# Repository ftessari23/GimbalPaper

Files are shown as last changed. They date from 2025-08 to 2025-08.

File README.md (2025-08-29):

# Gimbal Device

This repository contains the design files and assembly details for the **Gimbal apparatus** used in our recent publication. The device was developed to study human wrist rotations in both **kinematics** and **dynamics** experiments.  

## 📂 Repository Contents
- **`BoM.xlsx`**  
  Bill of Materials (BoM) listing the off-the-shelf components used. These are the exact parts I sourced (U.S.-based suppliers), but they are **not the only options**—equivalent components may be substituted.  

- **`.sldprt` files**  
  Individual **SolidWorks part files** for each component.  

- **`.sldasm` file**  
  Complete **SolidWorks assembly file** for the gimbal system.  

- **`.stl` files**  
  Components for **3D printing**. I printed them on a **Bambu FDM printer** with PLA filament.  
  - Recommended infill: **60–75%** for structural strength.  
  - Settings may be tuned depending on intended use.  

## ⚠️ Notes & Limitations
- The current design is **functional but not perfect**.  
- The **handle–fork connection** is the weakest point and has been the main failure site in testing.  
- The apparatus performs **reliably in pushing tasks** (as demonstrated in the paper).  
- It is **not recommended for pulling tasks**, as the handle–fork connection is likely to fail under tensile loads.  

## 🔧 Future Improvements
- Reinforcement or redesign of the **handle–fork interface**.  
- Optimization of the printed components for higher fatigue resistance.  

## 🌍 Applications
This gimbal system may be useful for researchers interested in:  
- Studying **human wrist rotations**.  
- Designing experiments involving **joint kinematics** or **interaction dynamics**.  
- Exploring applications in **rehabilitation robotics** and **biomechanics**.  

## 🤝 Contributions
Feel free to **edit, improve, or update** any part of the design. Contributions and forks are welcome to refine the apparatus for broader use.  

## 📖 Citation
If you use this design in your work, please cite the associated publication:

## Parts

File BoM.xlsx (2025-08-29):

Provider | Name | Order nr | Quantity | Link | Price/pc. ($) | Price total ($)
McMaster Carr | Ultra-Thin Ball Bearing: 440 Stainless Steel Ring, Open, 10mm Shaft Diameter and 22mm Housing ID | 6656K75 | 4 | https://www.mcmaster.com/6656K75/ | 16.12 | 64.48
McMaster Carr | Permanently Lubricated Ball Bearing: Open, Trade Number 6001, for 12 mm Shaft Diameter | 2349K213 | 4 | https://www.mcmaster.com/2349K213/ | 21.7 | 86.8
McMaster Carr | One-Piece Thrust Ball Bearing Shielded, for 5/16" Shaft Diameter, 11/16" OD | 60715K111 | 2 | https://www.mcmaster.com/60715K111/ | 48.72 | 97.44
McMaster Carr | Inline Ball Joint Linkage M8 x 1.25 mm Thread | 8412K12 | 2 | https://www.mcmaster.com/8412K12/ | 11.7 | 23.4
McMaster Carr | External Retaining Ring for 8 mm OD, DIN 1.4122 Stainless Steel | 90967A120 | 1 | https://www.mcmaster.com/90967A120/ | 7.66 | 7.66
McMaster Carr | Headless Clevis Pin with Retaining Ring Groove 18-8 Stainless Steel, 4 mm Diameter, 24 mm Usable Length | 93890A731 | 2 | https://www.mcmaster.com/93890A731/ | 10.64 | 21.28
McMaster Carr | Clevis Pin with Retaining Ring Groove 18-8 Stainless Steel, 6 mm Diameter, 28 mm Usable Length | 92735A112 | 1 | https://www.mcmaster.com/92735A112/ | 8.45 | 8.45
McMaster Carr | Clevis Pin with Retaining Ring Groove 18-8 Stainless Steel, 6 mm Diameter, 33 mm Usable Length | 92735A113 | 1 | https://www.mcmaster.com/92735A113/ | 9.58 | 9.58
McMaster Carr | External Retaining Ring for 12 mm OD, Zinc-Chromate-Plated Spring Steel | 90154A273 | 1 | https://www.mcmaster.com/90154A273/ | 11.77 | 11.77
 |  |  |  |  | TOTAL ($) | 254.61

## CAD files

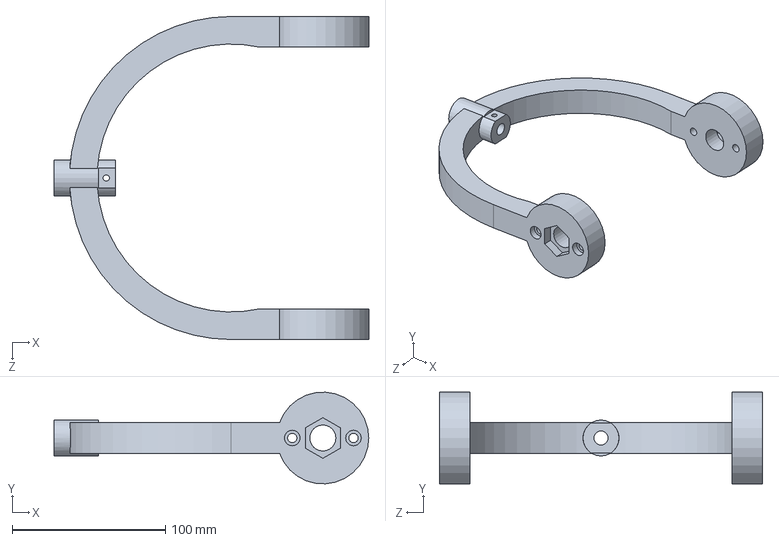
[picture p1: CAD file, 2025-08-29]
fork.SLDPRT
205.5 x 59.9 x 211.0 mm

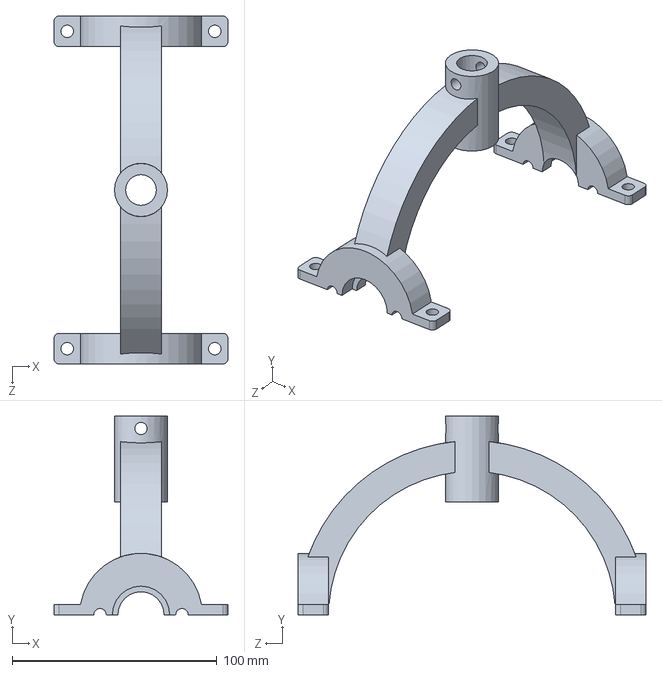
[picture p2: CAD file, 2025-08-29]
top_orbit.SLDPRT
85.0 x 97.0 x 170.0 mm

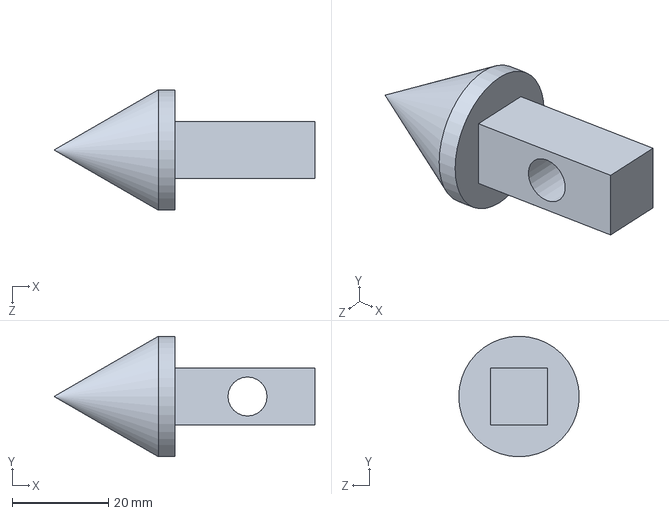
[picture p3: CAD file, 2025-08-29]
tool_end.SLDPRT
54.2 x 25.0 x 25.0 mm

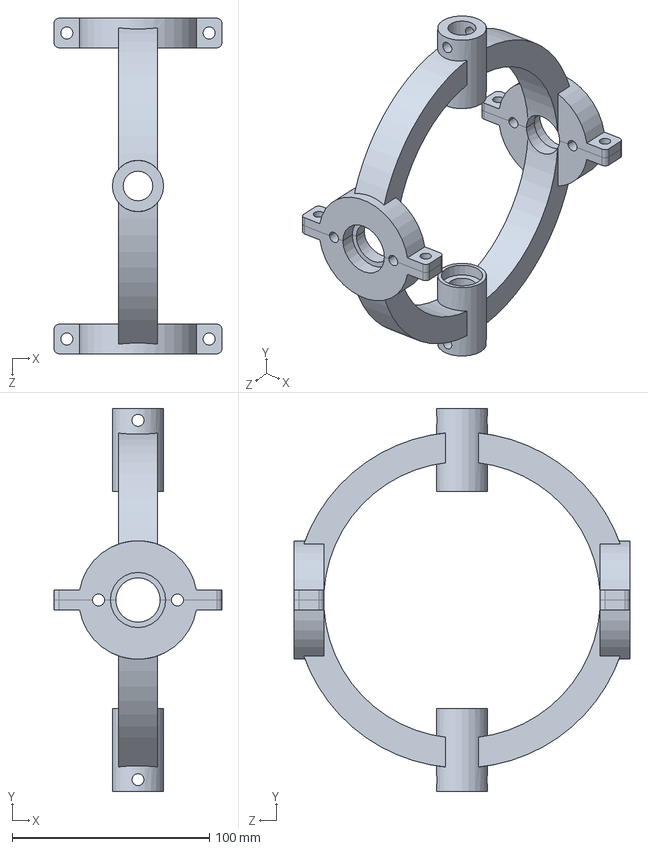
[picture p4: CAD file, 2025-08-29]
orbit.SLDPRT
85.0 x 194.0 x 170.0 mm

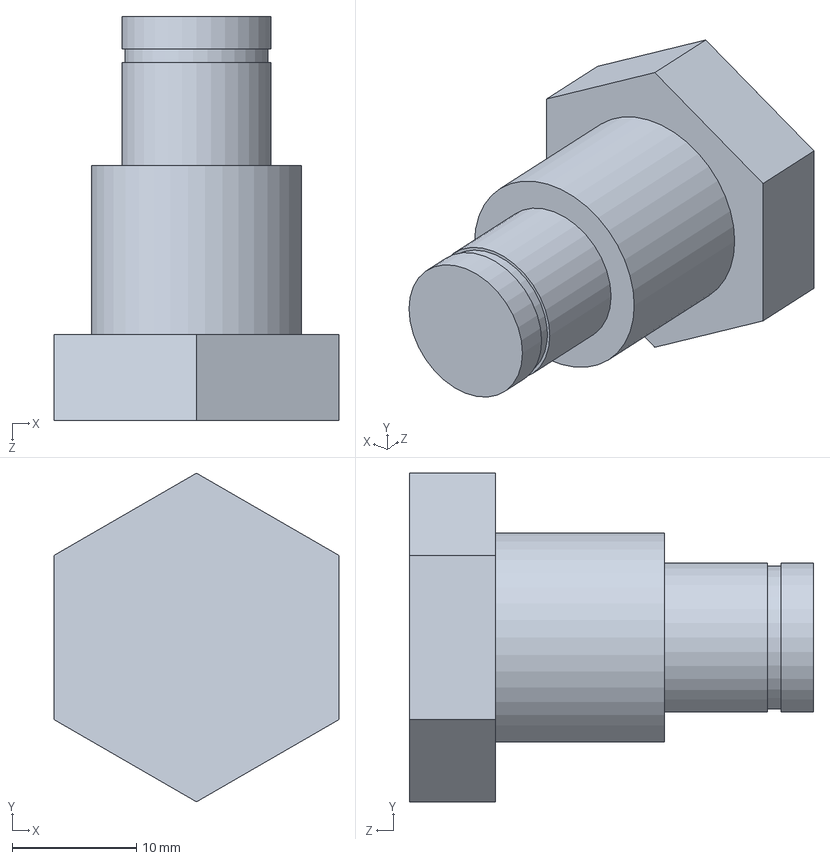
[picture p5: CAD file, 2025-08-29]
pin.SLDPRT
22.9 x 26.4 x 32.5 mm

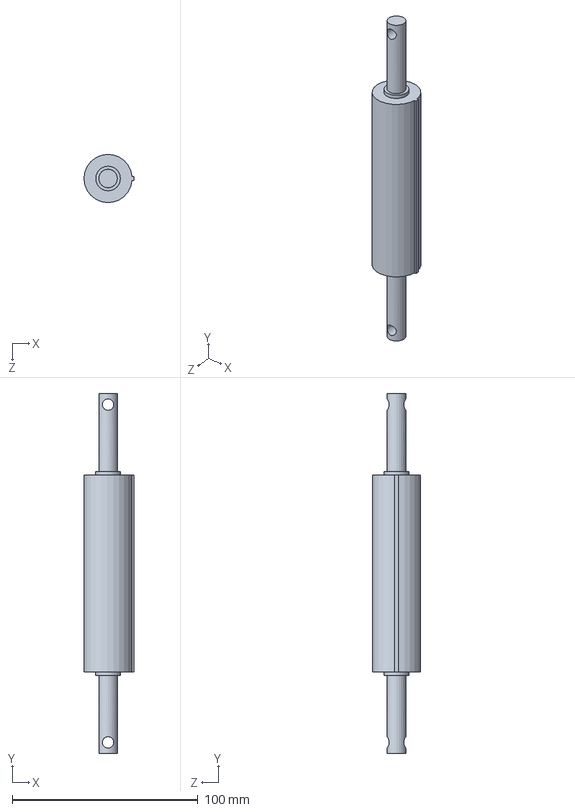
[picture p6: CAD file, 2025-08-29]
handle.SLDPRT
27.0 x 194.0 x 26.0 mm

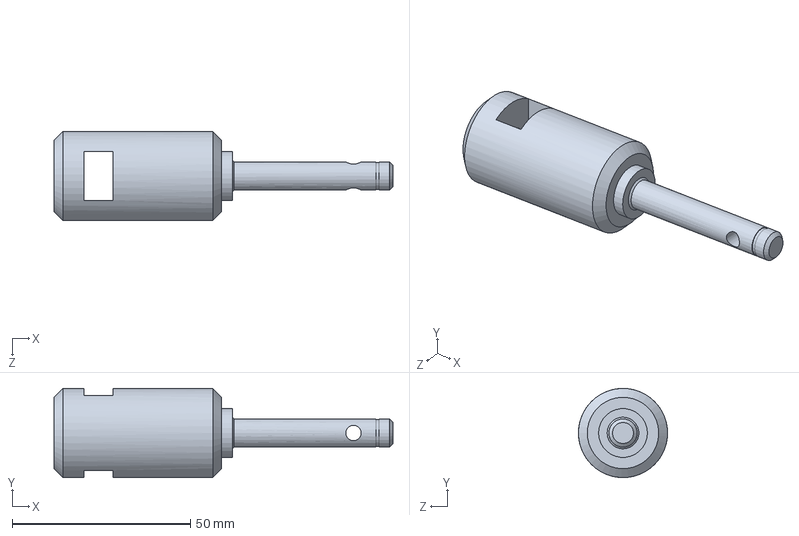
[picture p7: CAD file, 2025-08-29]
tool_v1.SLDPRT
95.0 x 25.0 x 25.0 mm

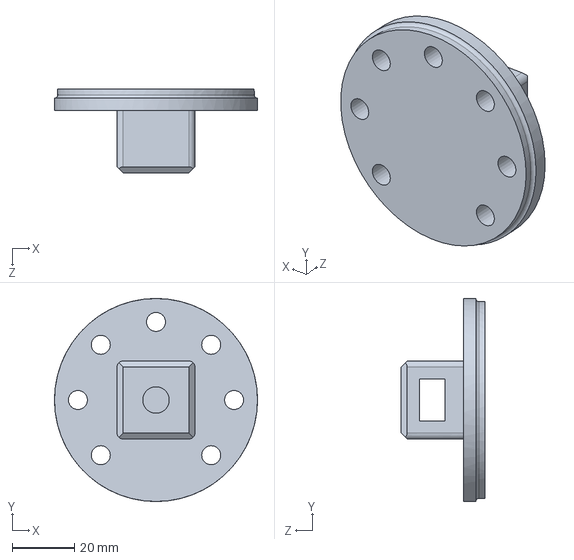
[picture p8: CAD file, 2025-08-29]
iiwa_connector.SLDPRT
65.0 x 65.0 x 27.0 mm

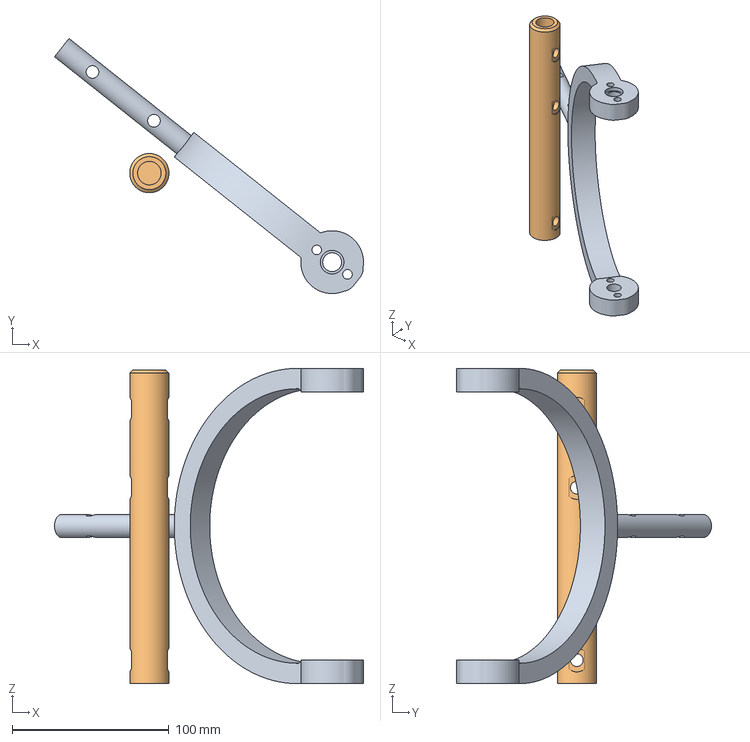
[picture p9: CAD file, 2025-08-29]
3d_wrist_IIpart.3mf
197.0 x 162.6 x 201.0 mm
fork.STL
tool_v1.STL

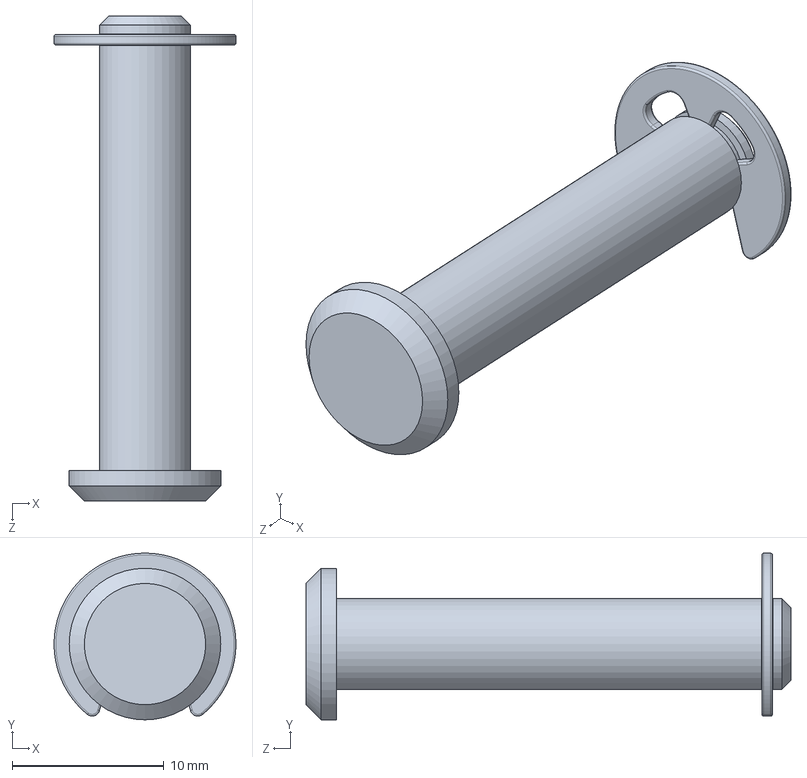
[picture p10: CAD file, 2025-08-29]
92735A112_Clevis Pin with Retaining Ring Groove.SLDPRT
12.0 x 11.0 x 32.0 mm

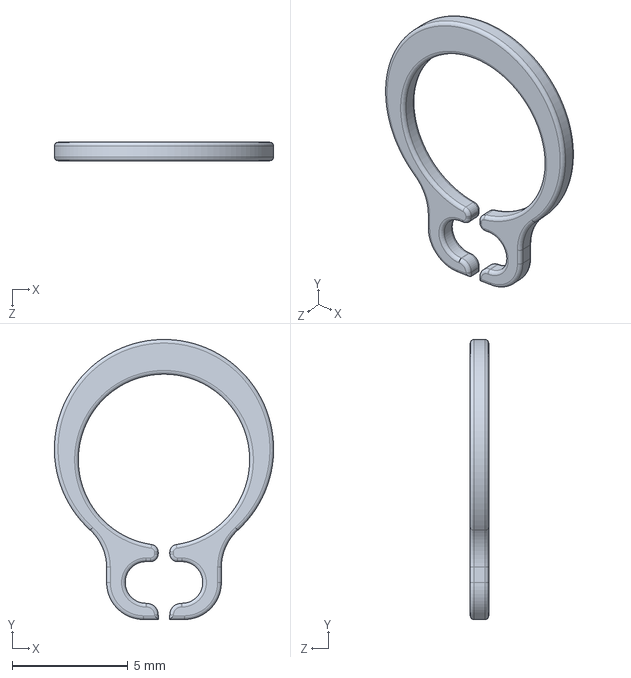
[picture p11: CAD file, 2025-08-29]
90967A120_External Retaining Ring.SLDPRT
9.47 x 12.1 x 0.8 mm

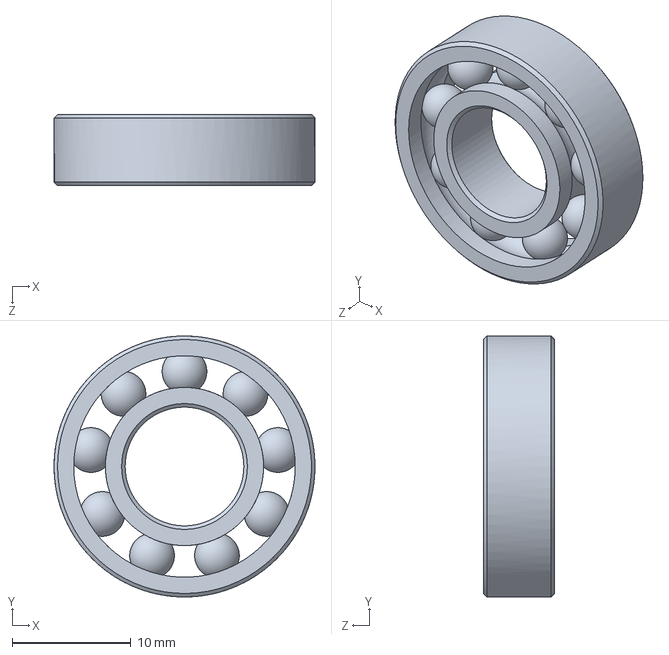
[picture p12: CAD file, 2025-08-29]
6656K75_Ultra-Thin Ball Bearing.SLDPRT
22.0 x 22.0 x 6.00 mm

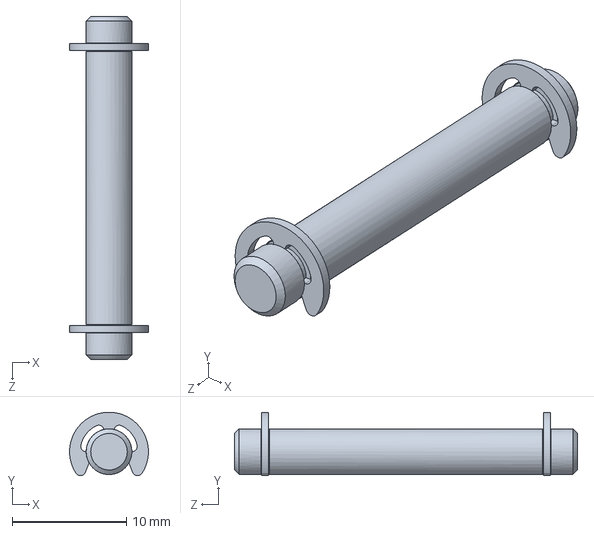
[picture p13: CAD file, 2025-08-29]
93890A731_Headless Clevis Pin with Retaining Ring Groove.SLDPRT
6.90 x 5.55 x 30.0 mm

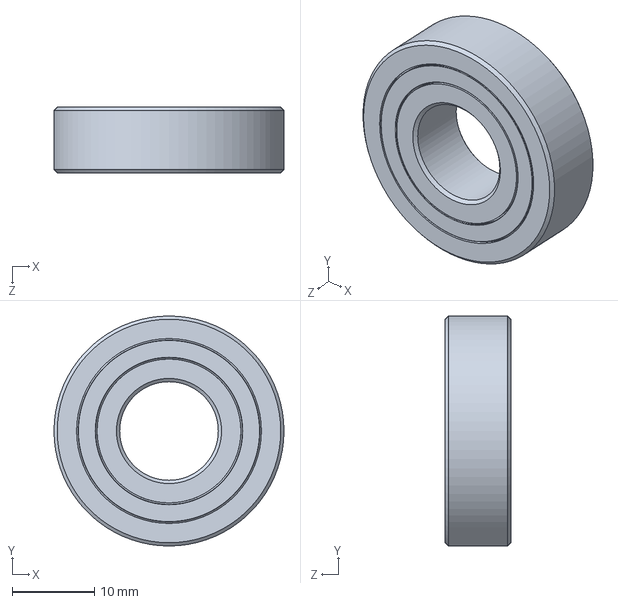
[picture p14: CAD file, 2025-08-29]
2349K213_Permanently Lubricated Ball Bearing.SLDPRT
28.0 x 28.0 x 8.00 mm

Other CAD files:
wall.SLDPRT
bottom_orbit.SLDPRT
90154A273_External Retaining Ring.SLDPRT
60715K111_One-Piece Steel Thrust Ball Bearing.SLDPRT
8412K12_Inline Ball Joint Linkage.SLDPRT
92735A113_Clevis Pin with Retaining Ring Groove.SLDPRT
bottom_orbit.STL
fork.STL
handle.STL
iiwa_connector.STL
pin.STL
tool_v1.STL
top_orbit.STL
